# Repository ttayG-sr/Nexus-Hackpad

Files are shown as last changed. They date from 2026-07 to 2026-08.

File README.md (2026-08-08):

# Nexus-Hackpad
  Nexus Pad is a 9-key macro pad with a rotary encoder and an OLED, with the switches illuminated by LED backlighting! It is made for compact keyboard gaming, specifically Valorant, and, in the future, a Home Control Panel for smart devices; it functions using QMK firmware.

## Features:
- 9 MX-Style switches
  
- Rotary Encoder
  
- 0.91 inch, 128x32 OLED Screen
  
- 9 SK6812 Mini-E LEDs
  
- 70mm x 100mm Custom PCB
  
- 2 Part Custom Case
  
- All brought together with the Seeed XIAO RP2040 using QMK firmware
  
## CAD Model:
  It is made with a sandwich-style mount, using supports to elevate the PCB so the USB port can fit, and the switches and everything else have the necessary tolerance. 

  The PCB is sandwiched between the bottom case, which has the supports, and the top plate, all fastened with M3 Heat Inserts and screws.
Additionally, I rounded everything for moderate viewing angles for the OLED and a more aesthetic look.

Screenshot 2026-07-10 at 6 52 28 PM

<p align="center">Exploded View:</p>

Screenshot 2026-07-10 at 6 53 29 PM

## PCB:
This is the PCB that connects all of my components and houses the brain of the Nexus Pad; it was all made in KiCAD.

<p align="center">Schematic:</p>

Screenshot 2026-08-08 at 1 23 13 AM

<p align="center">PCB:</p>

<p align="center">
  Screenshot 2026-08-08 at 1 25 10 AM
</p>

## Firmware Overview:

The Nexus Pad uses QMK (https://qmk.fm/) to operate.

- Key Bindings
  - 4 for abilities in Valorant
  - A Left Shift to walk in Valorant
  - Another layer in the future will be added for productivity tools
  - Will include support for VIA in the future for more customizability!
- The rotary encoder can control the volume; the press function doesn't work.
- I plan for the OLED to show CPU and GPU temperatures in the future using plugins, but for now it just displays "Nexus Pad"
- The LEDs have three lighting effects: breathing, rainbow mood, and snake.

## BOM:
- 1x SEEED Xiao RP2040
- 9x 1N4148 DO-35 Diodes
- 9x MX-Style switches
- 9x DSA Keycaps
- 9x SK6812 MINI-E LEDs
- 1x EC11 Rotary Encoder
- 1x 0.91" 128x32 OLED Display
- 1x PCB
- 4x M3x16mm screws
- 4x M3x5mx4mm heatset inserts
- 1x Bottom case (3D Printed)
- 1x Top plate (3D Printed)

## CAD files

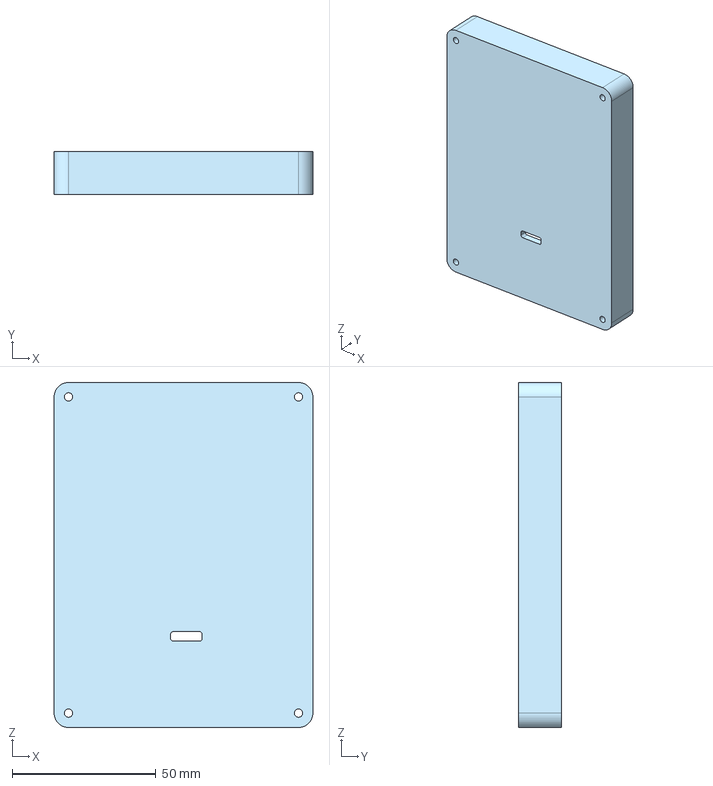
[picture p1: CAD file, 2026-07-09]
Production/Bottom Case.step
90.0 x 15.0 x 120.0 mm

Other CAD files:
Production/Top Plate.step

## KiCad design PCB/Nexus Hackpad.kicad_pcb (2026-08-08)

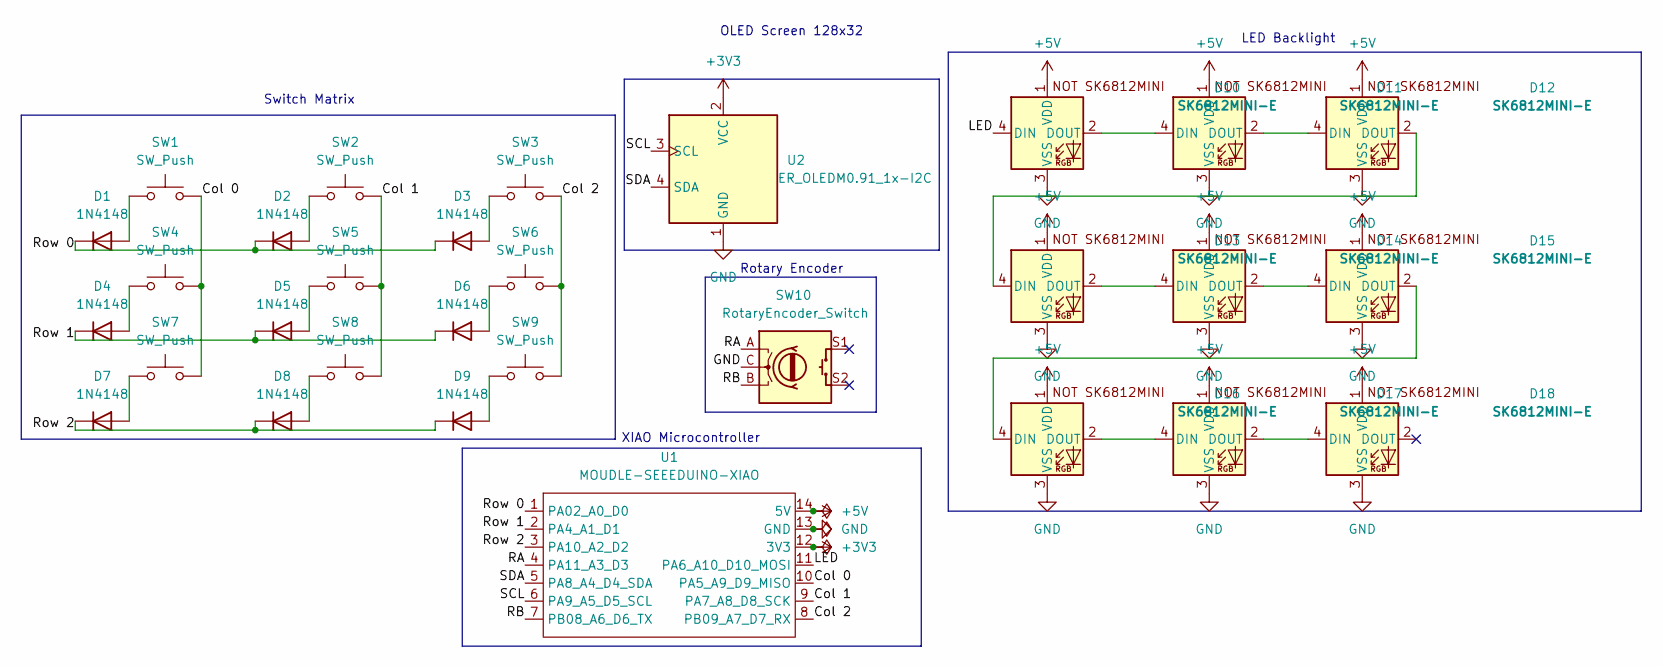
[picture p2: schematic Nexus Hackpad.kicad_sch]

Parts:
D1, D2, D3, D4, D5, D6, D7, D8, D9: 1N4148; D_DO-35_SOD27_P7.62mm_Horizontal
D10, D11, D12, D13, D14, D15, D16, D17, D18: SK6812MINI-E; SK6812MINI-E_fixed
SW1, SW2, SW3, SW4, SW5, SW6, SW7, SW8, SW9: SW_Push; SW_Cherry_MX_1.00u_PCB
SW10: RotaryEncoder_Switch; RotaryEncoder_Alps_EC11E-Switch_Vertical_H20mm
U1: MOUDLE-SEEEDUINO-XIAO; XIAO-Generic-Hybrid-14P-2.54-21X17.8MM
U2: ER_OLEDM0.91_1x-I2C

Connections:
+3V3: U1.12 (3V3), U2.2 (VCC)
+5V: D10.1 (VDD), D11.1 (VDD), D12.1 (VDD), D13.1 (VDD), D14.1 (VDD), D15.1 (VDD), D16.1 (VDD), D17.1 (VDD), D18.1 (VDD), U1.14 (5V)
/Col 0: SW1.2, SW4.2, SW7.2, U1.10 (PA5_A9_D9_MISO)
/Col 1: SW2.2, SW5.2, SW8.2, U1.9 (PA7_A8_D8_SCK)
/Col 2: SW3.2, SW6.2, SW9.2, U1.8 (PB09_A7_D7_RX)
/LED: D10.4 (DIN), U1.11 (PA6_A10_D10_MOSI)
/RA: SW10.A, U1.4 (PA11_A3_D3)
/RB: SW10.B, U1.7 (PB08_A6_D6_TX)
/Row 0: D1.1 (K), D2.1 (K), D3.1 (K), U1.1 (PA02_A0_D0)
/Row 1: D4.1 (K), D5.1 (K), D6.1 (K), U1.2 (PA4_A1_D1)
/Row 2: D7.1 (K), D8.1 (K), D9.1 (K), U1.3 (PA10_A2_D2)
/SCL: U1.6 (PA9_A5_D5_SCL), U2.3 (SCL)
/SDA: U1.5 (PA8_A4_D4_SDA), U2.4 (SDA)
GND: D10.3 (VSS), D11.3 (VSS), D12.3 (VSS), D13.3 (VSS), D14.3 (VSS), D15.3 (VSS), D16.3 (VSS), D17.3 (VSS), D18.3 (VSS), SW10.C, U1.13 (GND), U2.1 (GND)
unnamed: D1.2 (A), SW1.1
unnamed: D2.2 (A), SW2.1
unnamed: D3.2 (A), SW3.1
unnamed: D4.2 (A), SW4.1
unnamed: D5.2 (A), SW5.1
unnamed: D6.2 (A), SW6.1
unnamed: D7.2 (A), SW7.1
unnamed: D8.2 (A), SW8.1
unnamed: D9.2 (A), SW9.1
unnamed: D10.2 (DOUT), D11.4 (DIN)
unnamed: D11.2 (DOUT), D12.4 (DIN)
unnamed: D12.2 (DOUT), D13.4 (DIN)
unnamed: D13.2 (DOUT), D14.4 (DIN)
unnamed: D14.2 (DOUT), D15.4 (DIN)
unnamed: D15.2 (DOUT), D16.4 (DIN)
unnamed: D16.2 (DOUT), D17.4 (DIN)
unnamed: D17.2 (DOUT), D18.4 (DIN)

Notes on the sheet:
Rotary Encoder
XIAO Microcontroller
LED Backlight
OLED Screen 128x32
Switch Matrix

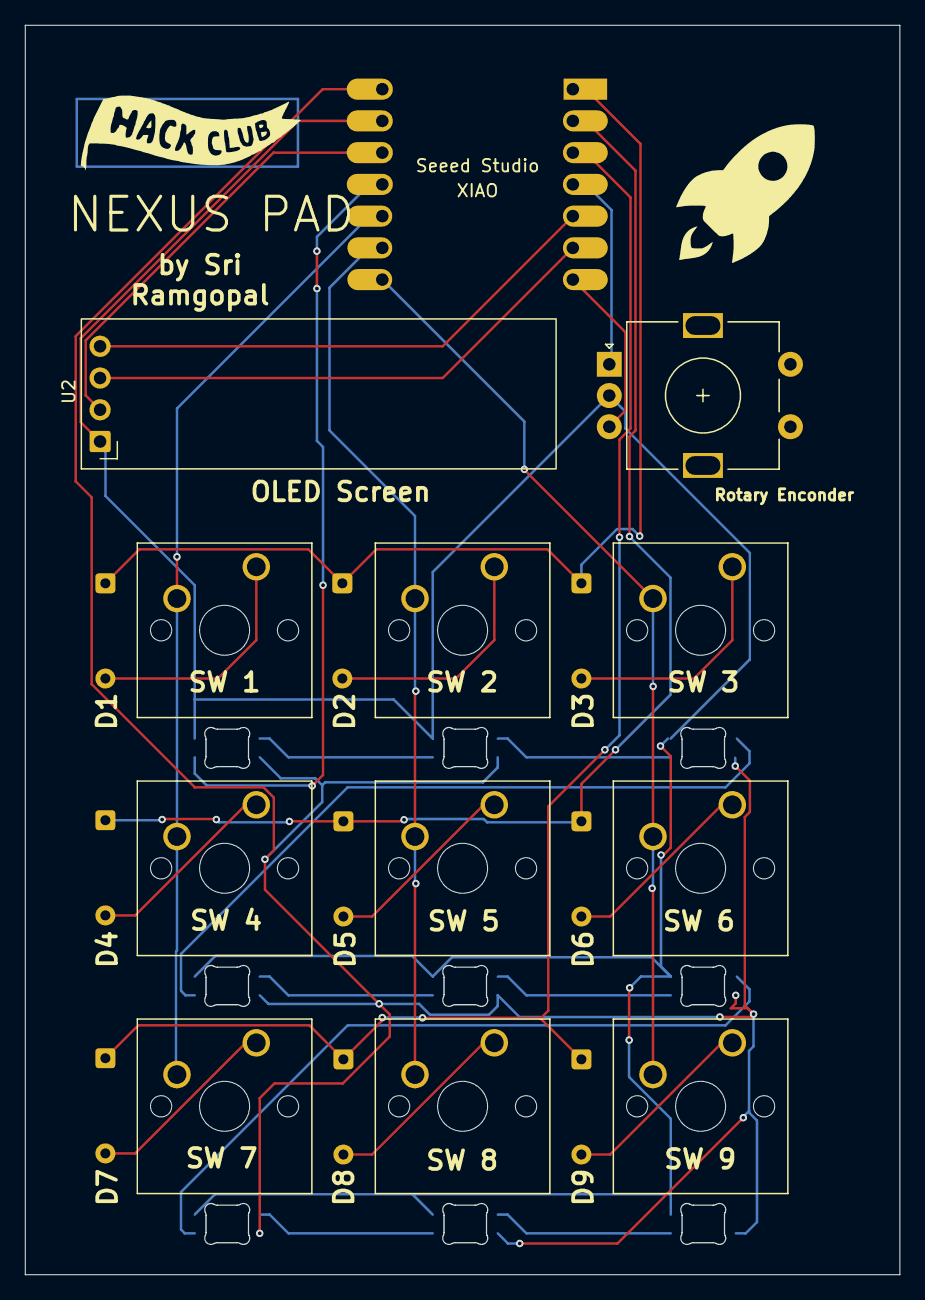
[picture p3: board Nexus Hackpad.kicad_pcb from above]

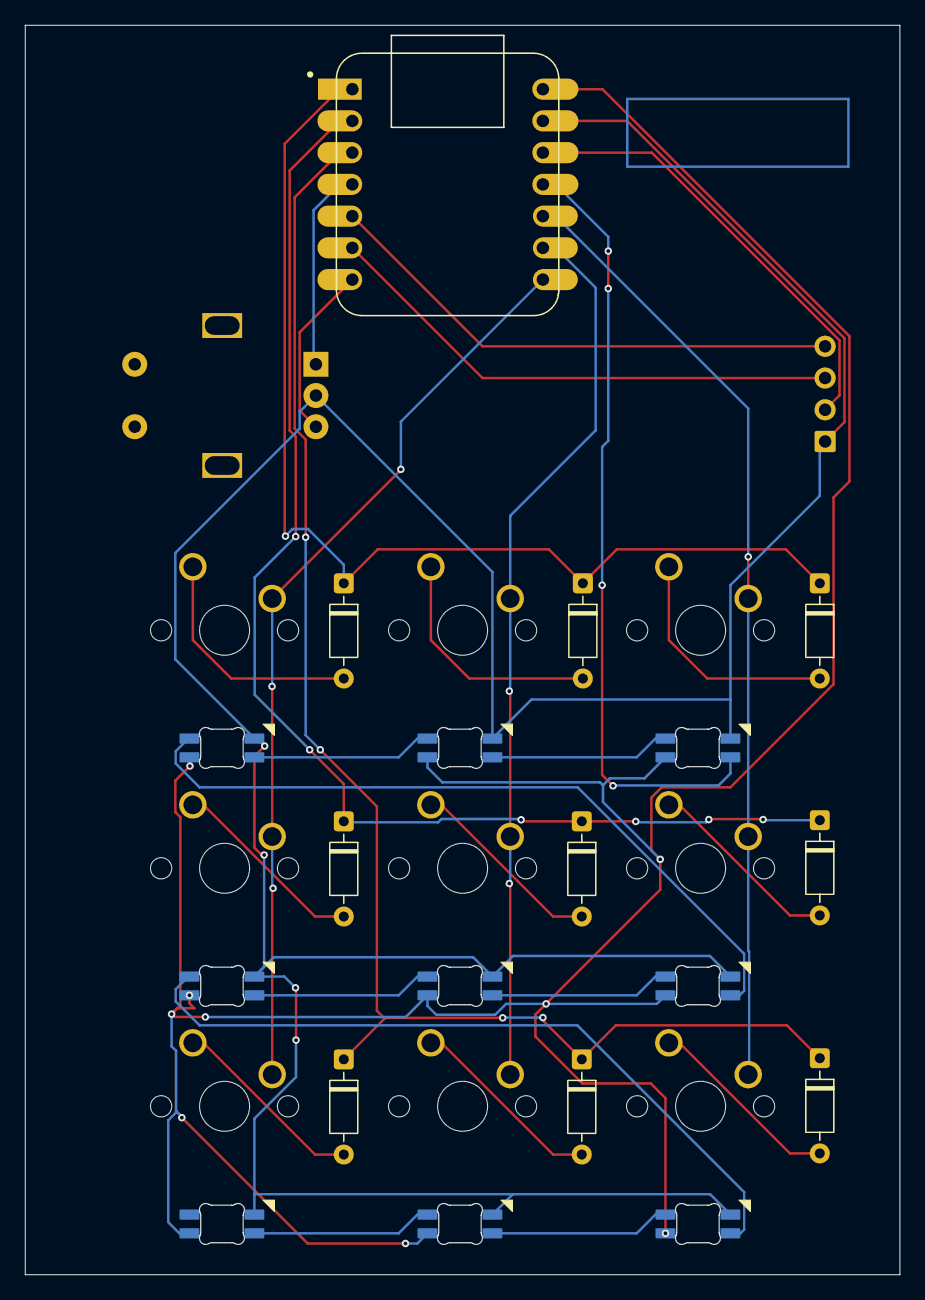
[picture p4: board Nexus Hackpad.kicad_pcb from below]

Board: 2 copper layers, 70.0 x 100.0 mm, 30 parts (10 on the bottom side), 31 nets.

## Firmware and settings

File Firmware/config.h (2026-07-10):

#pragma once

#define NUM_ENCODERS 1 

// Bootmagic Lite configuration
#define BOOTMAGIC_LITE_ROW 0
#define BOOTMAGIC_LITE_COLUMN 0

// OLED configuration
#define I2C_DRIVER I2CD1
#define I2C1_SDA_PIN GP6
#define I2C1_SCL_PIN GP7
#define OLED_TIMEOUT 0

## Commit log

2026-07-09 Create CAD
2026-07-09 Rename Nexus Hackpad.kicad_prl to PCB/Nexus Hackpad.kicad_prl
2026-07-09 Rename Nexus Hackpad.kicad_pcb to PCB/Nexus Hackpad.kicad_pcb
    [Nexus Hackpad.kicad_pcb]
2026-07-09 Rename Nexus Hackpad.kicad_sch to PCB/Nexus Hackpad.kicad_sch
    [Nexus Hackpad.kicad_sch]
2026-07-09 Rename Nexus Hackpad.kicad_pro to PCB/Nexus Hackpad.kicad_pro
2026-07-09 Move 48MB file into CAD directory
2026-07-09 Rename Bottom Case.step to Production/Bottom Case.step
    [Bottom Case.step]
2026-07-09 Rename Top Plate.step to Production/Top Plate.step
    [Top Plate.step]
2026-07-10 Update switch pin errors and redo uf2 file
2026-07-11 Initial work on README, only images and some stuff, no firmware.
    Added detailed information about the Nexus Pad, including its features, CAD model, and PCB design.
2026-07-11 Enhance README with features, firmware, and BOM details
    Added detailed features, firmware overview, and BOM for Nexus Pad.
2026-08-08 Change and Show Schematic Change of 5v to LEDs
2026-08-08 Show PCB Edior Change of LEDs to 5V
